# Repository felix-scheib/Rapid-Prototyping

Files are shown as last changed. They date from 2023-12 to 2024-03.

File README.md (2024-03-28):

# Rapid Prototyping

This is the repository with my prototype of [Rapid Prototyping](https://obs.fbi.h-da.de/mhb/modul.php?nr=30.2670&sem=20231) by [Prof. Dr. Stefan Rapp](https://fbi.h-da.de/personen/stefan-rapp/) in the winterterm 23/24.

The following tools are used to create the prototype:

- [PlatformIO](https://platformio.org/)
- [KiCad](https://www.kicad.org/)
- [FreeCAD](https://www.freecad.org/)

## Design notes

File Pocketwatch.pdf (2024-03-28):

# RAPID PROTOTYPING

Felix Scheib
WiSe 23/24
Prof. Dr. Stefan Rapp

# DIE IDEE

## ZIELSETZUNG

„Entangled Hearts“

- zwei Objekte, welche miteinander verbunden/“verschränkt“ sind
- Interaktion an einem Objekt ist am anderen sichtbar
- Kommunikation über weite Distanzen in „Echtzeit“ möglich
Felix Scheib - Rapid Prototyping - WiSe 23/24 | 3

## IDEENFINDUNG

Technik als Modeaccessoire

- Vorreiter: Apple
- Smartphones/Watches, Kopfhörer mehr als „nur“ Technik
- lange Schlangen vor Läden bei Verkaufsstart
- Technik Teil des Outfits, z.B. Kopfhörer

Retro/Vintage

- Technik wird „wiederbelebt“
- Beispiel: Schallplatten
- Mode und Frisuren aus vergangenen Jahrzehnten „kommen wieder“
- ältere (und einfachere) Lösungen oftmals robuster als
„overengineerte“ moderne Ansätze
Felix Scheib- Rapid Prototyping Prototyping - WiSe 23/24 | 4

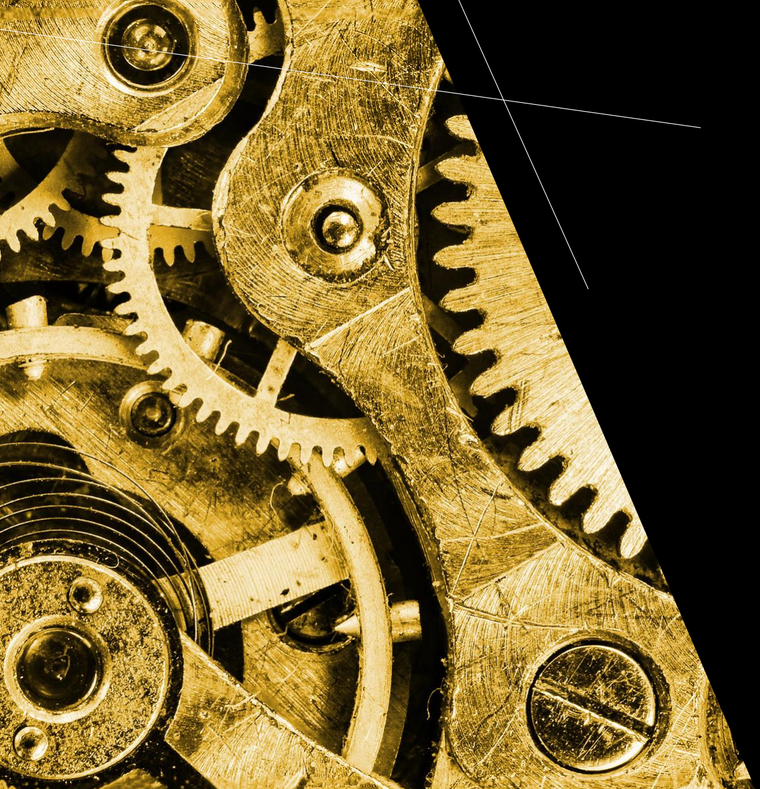
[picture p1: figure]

# THE NEXT „LITTLE“ THING

## POCKETWATCH 2.0

- Design einer klassischen Taschenuhr
- Display zum Anzeigen der Uhrzeit
- LED-Ring zur Kommunikation der Benutzer

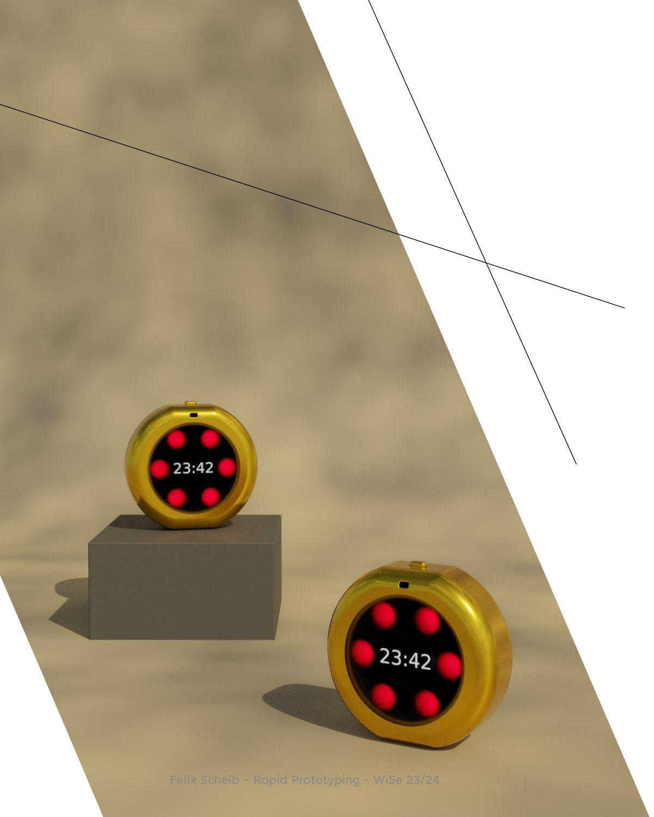
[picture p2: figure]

Felix Scheib - Rapid Prototyping - WiSe 23/24 | 6

## VORTEILE DER POCKETWATCH 2.0

Die Zeit ist ein fundamentaler Bestandteil unseres Alltags

- unser Alltag wird durch Termine strukturiert (z.B. Stundenplan)
- für die aktuelle Uhrzeit nutzt man hauptsächlich Smartphones und Smartwatches
- dauerhafte Präsenz dieser Geräte führt zur dauerhaften Erreichbarkeit (psychischer Stress)

Die Pocketwatch 2.0 führt zur Entschleunigung des Alltags!

Felix Scheib - Rapid Prototyping - WiSe 23/24 | 7

## TECHNISCHE UMSETZUNG

- (OLED) Display zum Anzeigen der Uhrzeit
- LED-Ring (Neopixel) zum Abspielen von Blinksequenzen
- Interaktion über Bewegungs- und Helligkeitssensor oder Taster
- Kommunikation mittels MQTT
- Aufladen des Akkus über USB-C
Felix Scheib - Rapid Prototyping - WiSe 23/24 | 8

## MATERIALKOSTEN

Position | Anzahl | Einzelpreis | Summe
Elektronik | 1 | 14,15€ | 14,15€
PCB | 1 | 0,41€ | 0,41€
Display | 1 | 1,27€ | 1,27€
MPU | 1 | 3,35€ | 3,35€
Glas | 1 | 2,10€ | 2,10€

PLA-
Filament | 42g | 0,03€ | 1,26€
Summe | | | 22,54€

Felix Scheib - Rapid Prototyping - WiSe 23/24

| | Anzahl | Einzelpreis | Summe
Kondensator | 470pF | 1 | 0,026 € | 0,026 €
| 0.1µF | 8 | 0,008 € | 0,064 €
| 470nF | 1 | 0,062 € | 0,062 €
| 1µF | 3 | 0,265 € | 0,795 €
| 4.7µF | 2 | 0,183 € | 0,366 €
| | | | 1,313 €
Widerstand | 330Ω | 2 | 0,001 € | 0,002 €
| 2kΩ | 1 | 0,001 € | 0,001 €
10kΩ | 4 | 0,001 € | 0,004 €
100kΩ | 1 | 0,001 € | 0,001 €
| | | 0,008 €
Licht | LED rot | 1 | 0,069 € | 0,069 €
Neopixel | 6 | 0,279 € | 1,671 €
Phototransistor | 1 | 0,279 € | 0,279 €
| | | 2,019 €
Konnektoren | Batterie | 1 | 0,274 € | 0,274 €
| Pin-Header 1x8 | 3 | 0,418 € | 1,254 €
USB-C | 1 | 0,331 € | 0,331 €
| | | 1,859 €
Schalter | Taster | 1 | 0,267 € | 0,267 €
| Schiebeschalter | 1 | 0,463 € | 0,463 €
| | | | 0,730 €
IC/MCU | Batterie Management | 1 | 0,593 € | 0,593 €
Leistungs Management | 1 | 0,207 € | 0,207 €
ESP32 | 1 | 3,240 € | 3,240 €
Akku | 1 | 4,180 € | 4,180 €
| | | 8,220 €
14,149 €

9

# SERIENMODELL

## FOKUS DES PROTOTYPS

- Platinen müssen per Hand zu löten sein (teilweise Einsatz von „Through-Hole“ Komponenten)
- einfacher Zugang zu Platinen im eingebauten Zustand
- Serielle Verbindung auch nach „Verlöten“ des Microchips (Pin-Header auf Rückseite)
- Gehäuse muss mit 3D-Drucker herstellbar sein
Felix Scheib - Rapid Prototyping - WiSe 23/24 | 11

## OPTIMIERUNGEN DES SERIENMODELLS

Haptik

- Materialwahl des Gehäuses (Metall, Composite)
- Herstellung des Gehäuses (Spritzguss, Fräsen)
- Gravur des Glases mit Laser
- Getöntes Glas
- Druckpunkt des Tasters

Elektronik

- nur Surface Mount (SMT)
Komponenten
- größerer Akku
- Passform des Akkus
- induktives Laden
- Solarpanel auf Rückseite
- (E)SIM statt WiFi für
Kommunikation
Felix Scheib Felix Scheib - Rapid Prototyping Prototyping - WiSe 23/24 | 12

# DEMONSTRATION DES PROTOTYPS

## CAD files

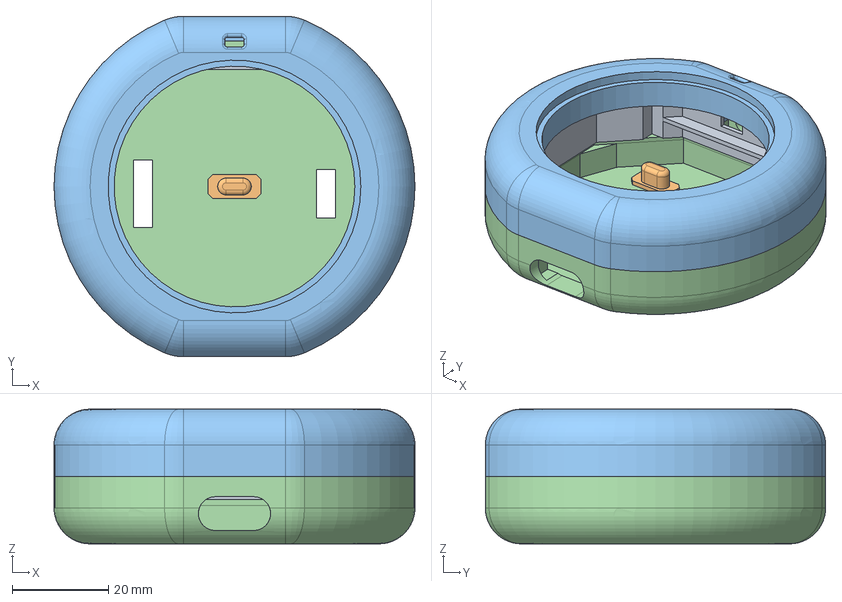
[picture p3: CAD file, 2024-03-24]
FreeCAD/EntangledHearts.FCStd
75.0 x 70.7 x 28.0 mm
Connector_Body
Button_Body
Top
Bottom

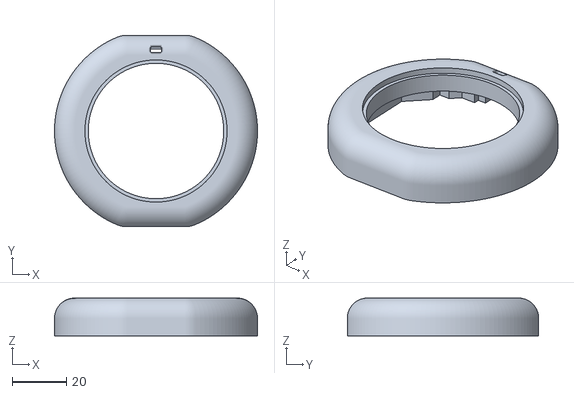
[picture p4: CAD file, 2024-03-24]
FreeCAD/STL/Top_Body.stl
75.0 x 70.7 x 14.0

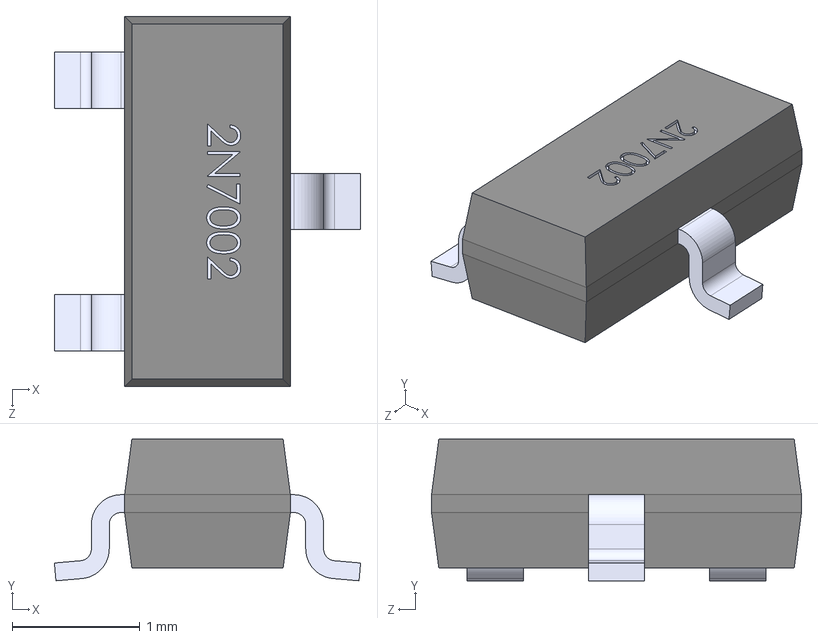
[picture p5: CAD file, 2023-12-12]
KiCad/_Libraries/2N7002/2N7002.stp
2.40 x 1.11 x 2.90 mm
2N7002_2
2N7002_3
2N7002_4
2N7002

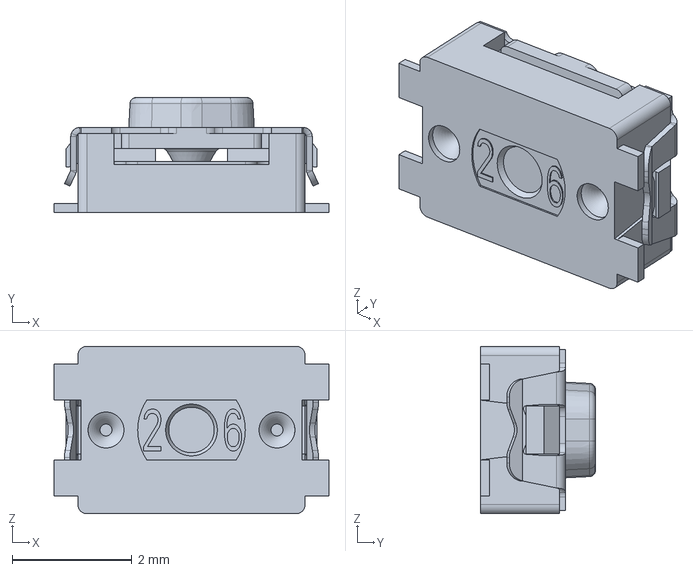
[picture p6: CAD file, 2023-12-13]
KiCad/_Libraries/KMR631NGULCLFS/KMR631NGULCLFS.stp
4.60 x 1.92 x 2.80 mm

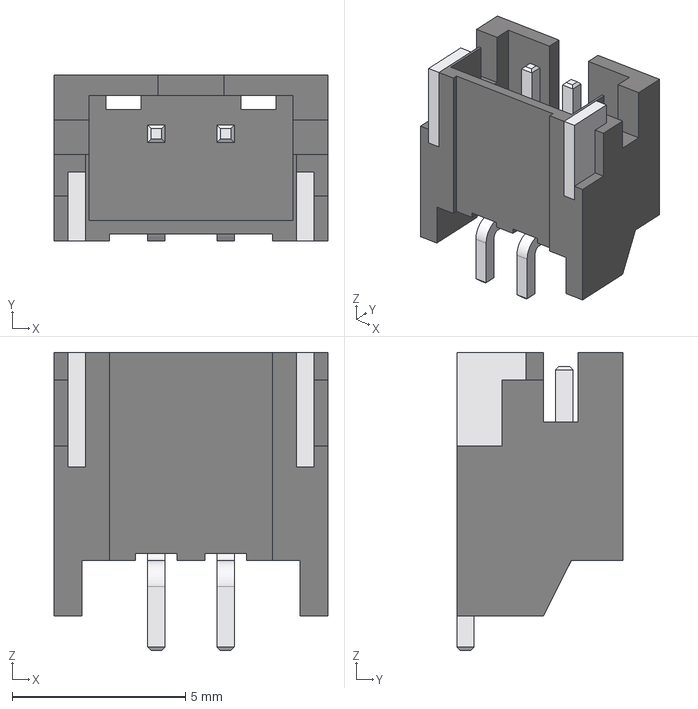
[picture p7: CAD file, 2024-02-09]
KiCad/_Libraries/S2B-PH-SM4-TB.stp
7.90 x 4.80 x 8.60 mm

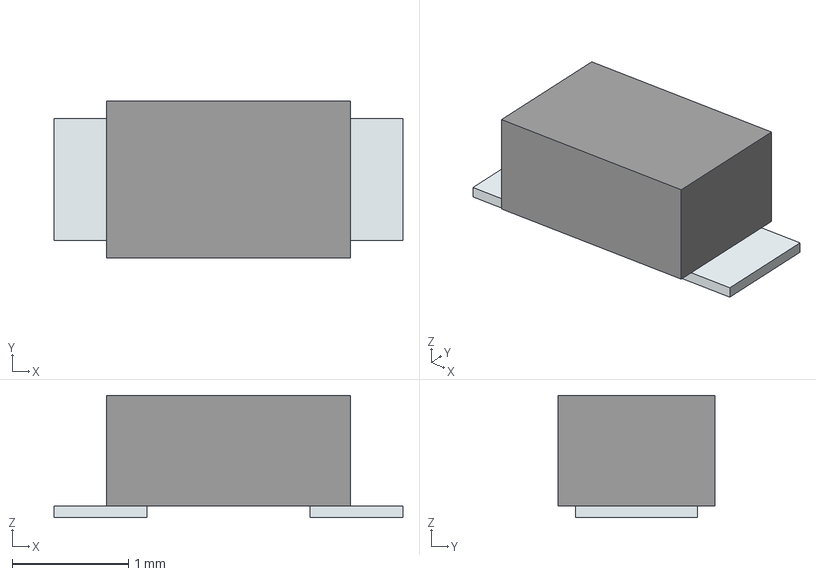
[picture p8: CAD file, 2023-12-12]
KiCad/_Libraries/SFH_3711/SFH_3711.stp
3.00 x 1.35 x 1.05 mm
Pins

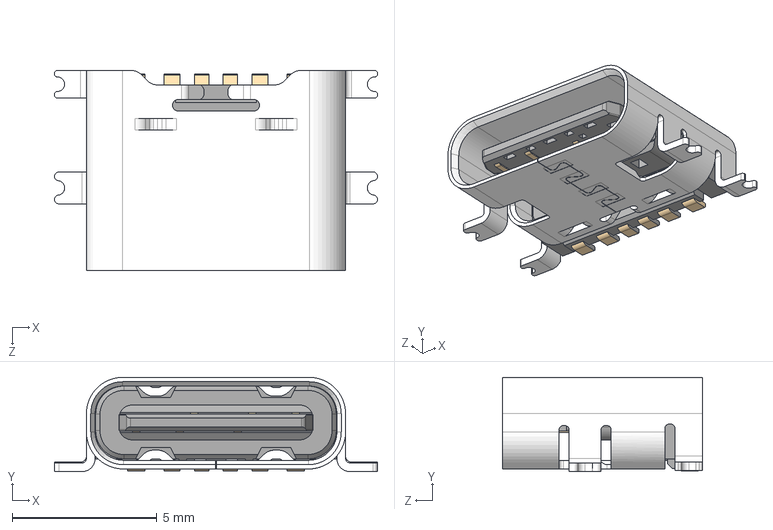
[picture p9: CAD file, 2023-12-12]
KiCad/_Libraries/USB4135-GF-A/USB4135-GF-A.stp
11.1 x 3.25 x 6.90 mm
USB4135-GF-A
USB4135-GF-A_2

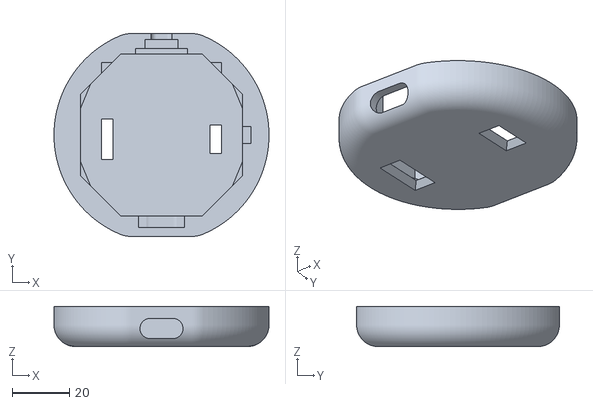
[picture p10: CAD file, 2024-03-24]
FreeCAD/STL/Bottom_Body.stl
75.0 x 70.7 x 14.0

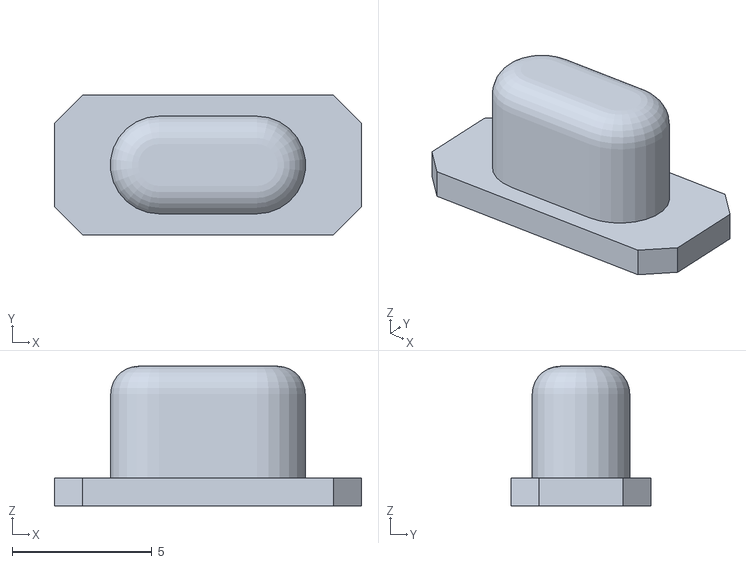
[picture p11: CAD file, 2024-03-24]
FreeCAD/STL/Button_Body.stl
11.0 x 5.00 x 5.00

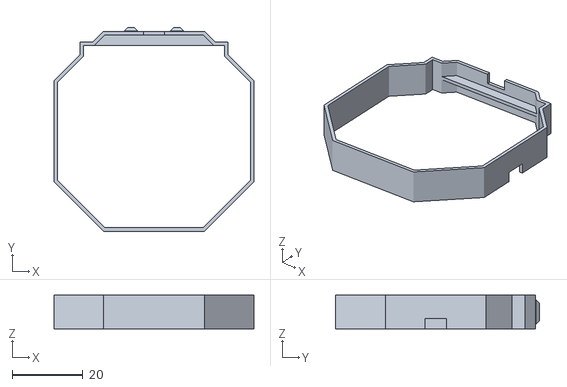
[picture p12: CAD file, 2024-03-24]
FreeCAD/STL/Connector_Body.stl
56.6 x 57.6 x 9.60

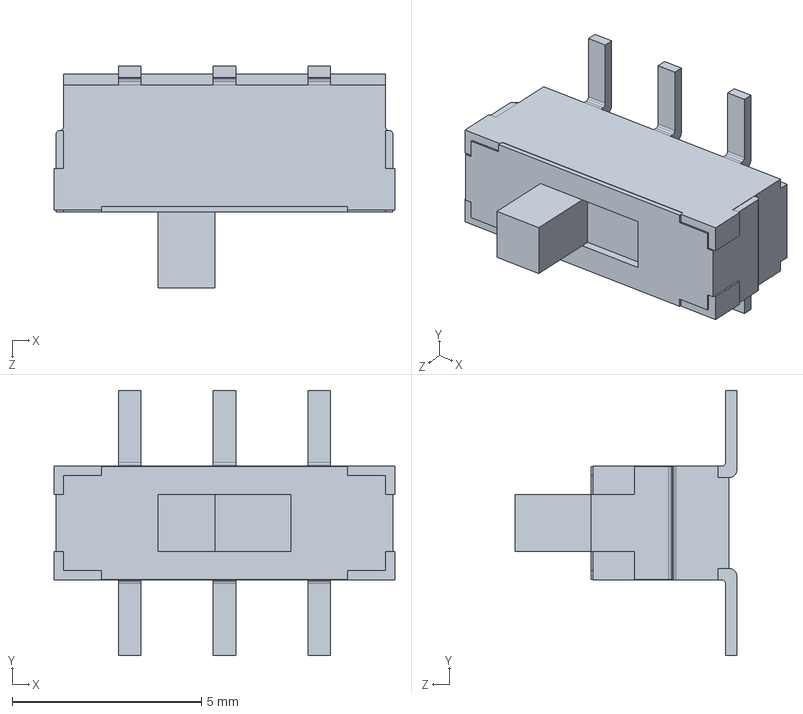
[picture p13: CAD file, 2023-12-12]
KiCad/_Libraries/JS202011SCQN/JS202011SCQN.stp
9.00 x 7.00 x 5.85 mm

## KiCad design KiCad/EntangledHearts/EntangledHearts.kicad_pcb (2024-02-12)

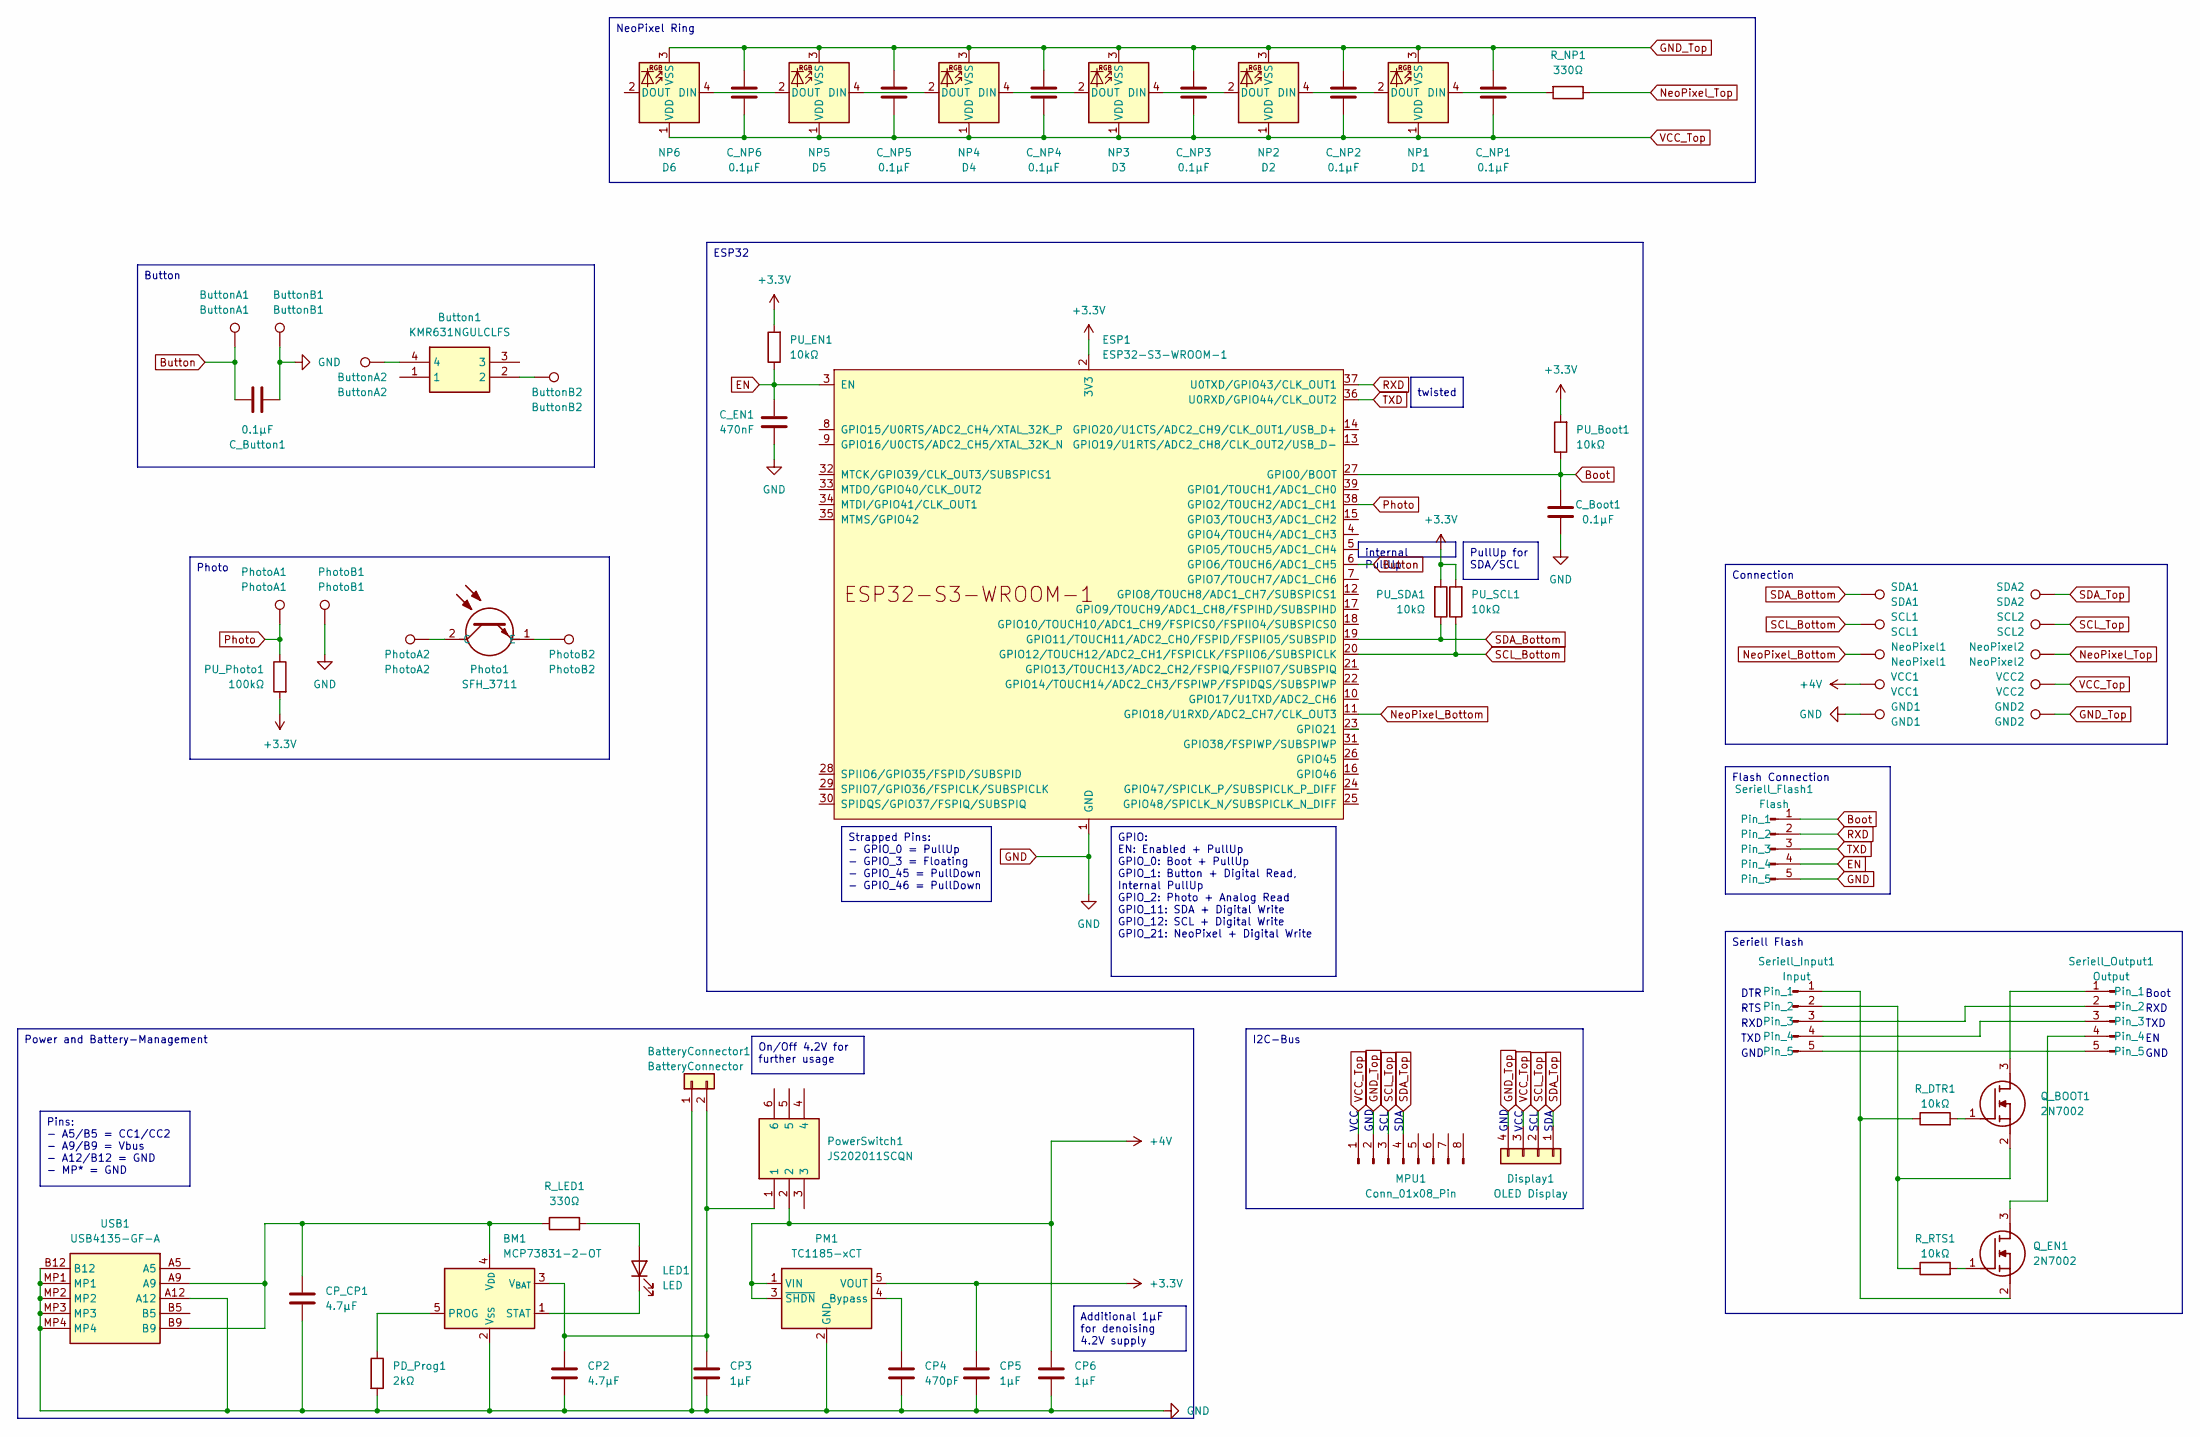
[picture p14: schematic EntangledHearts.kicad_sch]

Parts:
BM1: MCP73831-2-OT; SOT-23-5
BatteryConnector1: BatteryConnector; JST_PH_S2B-PH-SM4-TB_1x02-1MP_P2.00mm_Horizontal
Button1: KMR631NGULCLFS; KMR621NG; Mouser Part Number 611-KMR631NGULCLFS
ButtonA1: ButtonA1; TestPoint_Pad_1.5x1.5mm
ButtonA2: ButtonA2; TestPoint_Pad_1.5x1.5mm
ButtonB1: ButtonB1; TestPoint_Pad_1.5x1.5mm
ButtonB2: ButtonB2; TestPoint_Pad_1.5x1.5mm
CP2: 4.7µF; C_0805_2012Metric
CP3, CP5, CP6: 1µF; C_0805_2012Metric
CP4: 470pF; C_0805_2012Metric
CP_CP1: 4.7µF; C_0805_2012Metric
C_Boot1: 0.1µF; C_0805_2012Metric
C_Button1: 0.1µF; C_0805_2012Metric
C_EN1: 470nF; C_0805_2012Metric
C_NP1, C_NP2, C_NP3, C_NP4, C_NP5, C_NP6: 0.1µF; C_0805_2012Metric
D1: NP1; LED_WS2812B_PLCC4_5.0x5.0mm_P3.2mm
D2: NP2; LED_WS2812B_PLCC4_5.0x5.0mm_P3.2mm
D3: NP3; LED_WS2812B_PLCC4_5.0x5.0mm_P3.2mm
D4: NP4; LED_WS2812B_PLCC4_5.0x5.0mm_P3.2mm
D5: NP5; LED_WS2812B_PLCC4_5.0x5.0mm_P3.2mm
D6: NP6; LED_WS2812B_PLCC4_5.0x5.0mm_P3.2mm
Display1: OLED Display; PinHeader_1x04_P2.54mm_Vertical
ESP1: ESP32-S3-WROOM-1
GND1: GND1; TestPoint_Pad_1.5x1.5mm
GND2: GND2; TestPoint_Pad_1.5x1.5mm
LED1: LED; LED_0805_2012Metric
MPU1: Conn_01x08_Pin; PinHeader_1x08_P2.54mm_Vertical_SMD_Pin1Left
NeoPixel1: NeoPixel1; TestPoint_Pad_1.5x1.5mm
NeoPixel2: NeoPixel2; TestPoint_Pad_1.5x1.5mm
PD_Prog1: 2kΩ; R_0805_2012Metric
PM1: TC1185-xCT; SOT-23-5
PU_Boot1: 10kΩ; R_0805_2012Metric
PU_EN1: 10kΩ; R_0805_2012Metric
PU_Photo1: 100kΩ; R_0805_2012Metric
PU_SCL1: 10kΩ; R_0805_2012Metric
PU_SDA1: 10kΩ; R_0805_2012Metric
Photo1: SFH_3711; SFH3711; Mouser Part Number 720-SFH3711
PhotoA1: PhotoA1; TestPoint_Pad_1.5x1.5mm
PhotoA2: PhotoA2; TestPoint_Pad_1.5x1.5mm
PhotoB1: PhotoB1; TestPoint_Pad_1.5x1.5mm
PhotoB2: PhotoB2; TestPoint_Pad_1.5x1.5mm
PowerSwitch1: JS202011SCQN; Mouser Part Number 611-JS202011SCQN
Q_BOOT1: 2N7002; SOT96P240X120-3N; Manufacturer_Part_Number 2N7002; Mouser Part Number 512-2N7002
Q_EN1: 2N7002; SOT96P240X120-3N; Manufacturer_Part_Number 2N7002; Mouser Part Number 512-2N7002
R_DTR1: 10kΩ; R_0805_2012Metric
R_LED1: 330Ω; R_0805_2012Metric
R_NP1: 330Ω; R_0805_2012Metric
R_RTS1: 10kΩ; R_0805_2012Metric
SCL1: SCL1; TestPoint_Pad_1.5x1.5mm
SCL2: SCL2; TestPoint_Pad_1.5x1.5mm
SDA1: SDA1; TestPoint_Pad_1.5x1.5mm
SDA2: SDA2; TestPoint_Pad_1.5x1.5mm
Seriell_Flash1: Flash; PinHeader_1x05_P2.54mm_Vertical_SMD_Pin1Left
Seriell_Input1: Input; PinHeader_1x05_P2.54mm_Vertical_SMD_Pin1Left
Seriell_Output1: Output; PinHeader_1x05_P2.54mm_Vertical_SMD_Pin1Left
USB1: USB4135-GF-A; USB4135GFA; Mouser Part Number 640-USB4135-GF-A
VCC1: VCC1; TestPoint_Pad_1.5x1.5mm
VCC2: VCC2; TestPoint_Pad_1.5x1.5mm

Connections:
+3.3V: CP5.1, ESP1.2 (3V3), PM1.5 (VOUT), PU_Boot1.2, PU_EN1.2, PU_Photo1.2, PU_SCL1.2, PU_SDA1.2
+4V: CP6.1, PM1.1 (VIN), PM1.3 (~SHDN), PowerSwitch1.2, VCC1.1
Boot: C_Boot1.2, ESP1.27 (GPIO0/BOOT), PU_Boot1.1, Seriell_Flash1.1
Button: ButtonA1.1, C_Button1.1, ESP1.6 (GPIO6/TOUCH6/ADC1_CH5)
EN: C_EN1.2, ESP1.3 (EN), PU_EN1.1, Seriell_Flash1.4
GND: BM1.2 (V_{SS}), BatteryConnector1.1, ButtonB1.1, CP2.2, CP3.2, CP4.2, CP5.2, CP6.2, CP_CP1.2, C_Boot1.1, C_Button1.2, C_EN1.1, ESP1.1 (GND), ESP1.40 (GND), ESP1.41 (GND), GND1.1, PD_Prog1.2, PM1.2 (GND), PhotoB1.1, Seriell_Flash1.5, USB1.A12, USB1.B12, USB1.MP1, USB1.MP2, USB1.MP3, USB1.MP4
GND_Top: C_NP1.2, C_NP2.2, C_NP3.2, C_NP4.2, C_NP5.2, C_NP6.2, D1.3 (VSS), D2.3 (VSS), D3.3 (VSS), D4.3 (VSS), D5.3 (VSS), D6.3 (VSS), Display1.4, GND2.1, MPU1.2
NeoPixel_Bottom: ESP1.11 (GPIO18/U1RXD/ADC2_CH7/CLK_OUT3), NeoPixel1.1
NeoPixel_Top: NeoPixel2.1, R_NP1.1
unnamed: BM1.5 (PROG), PD_Prog1.1
unnamed: BM1.1 (STAT), LED1.1 (K)
unnamed: BM1.3 (V_{BAT}), BatteryConnector1.2, CP2.1, CP3.1, PowerSwitch1.1
unnamed: BM1.4 (V_{DD}), CP_CP1.1, R_LED1.1, USB1.A9, USB1.B9
unnamed: Button1.2, ButtonB2.1
unnamed: Button1.4, ButtonA2.1
unnamed: D1.4 (DIN), R_NP1.2
unnamed: D1.2 (DOUT), D2.4 (DIN)
unnamed: D2.2 (DOUT), D3.4 (DIN)
unnamed: D3.2 (DOUT), D4.4 (DIN)
unnamed: D4.2 (DOUT), D5.4 (DIN)
unnamed: D5.2 (DOUT), D6.4 (DIN)
unnamed: LED1.2 (A), R_LED1.2
unnamed: CP4.1, PM1.4 (Bypass)
unnamed: Photo1.2 (C), PhotoA2.1
unnamed: Photo1.1 (E), PhotoB2.1
unnamed: Q_BOOT1.3 (D), Seriell_Output1.1
unnamed: Q_BOOT1.1 (G), R_DTR1.2
unnamed: Q_BOOT1.2 (S), R_RTS1.1, Seriell_Input1.2
unnamed: Q_EN1.3 (D), Seriell_Output1.4
unnamed: Q_EN1.1 (G), R_RTS1.2
unnamed: Q_EN1.2 (S), R_DTR1.1, Seriell_Input1.1
unnamed: Seriell_Input1.3, Seriell_Output1.2
unnamed: Seriell_Input1.4, Seriell_Output1.3
unnamed: Seriell_Input1.5, Seriell_Output1.5
Photo: ESP1.38 (GPIO2/TOUCH2/ADC1_CH1), PU_Photo1.1, PhotoA1.1
RXD: ESP1.37 (U0TXD/GPIO43/CLK_OUT1), Seriell_Flash1.2
SCL_Bottom: ESP1.20 (GPIO12/TOUCH12/ADC2_CH1/FSPICLK/FSPIIO6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), PU_SCL1.1, SCL1.1
SCL_Top: Display1.2, MPU1.3, SCL2.1
SDA_Bottom: ESP1.19 (GPIO11/TOUCH11/ADC2_CH0/FSPID/FSPIIO5/S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), PU_SDA1.1, SDA1.1
SDA_Top: Display1.1, MPU1.4, SDA2.1
TXD: ESP1.36 (U0RXD/GPIO44/CLK_OUT2), Seriell_Flash1.3
VCC_Top: C_NP1.1, C_NP2.1, C_NP3.1, C_NP4.1, C_NP5.1, C_NP6.1, D1.1 (VDD), D2.1 (VDD), D3.1 (VDD), D4.1 (VDD), D5.1 (VDD), D6.1 (VDD), Display1.3, MPU1.1, VCC2.1

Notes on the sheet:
Additional 1µF for denoising 4.2V supply
Pins: - A5/B5 = CC1/CC2 - A9/B9 = Vbus - A12/B12 = GND - MP* = GND
On/Off 4.2V for further usage
Power and Battery-Management
Photo
I2C-Bus
ESP32
internal PullUp
PullUp for SDA/SCL
GPIO: EN: Enabled + PullUp GPIO_0: Boot + PullUp GPIO_1: Button + Digital Read, Internal PullUp GPIO_2: Photo + Analog Read GPIO_11: SDA + Digital Write GPIO_12: SCL + Digital Write GPIO_21: NeoPixel + Digital Write
Flash Connection
twisted
Seriell Flash
Connection
Strapped Pins: - GPIO_0 = PullUp - GPIO_3 = Floating - GPIO_45 = PullDown - GPIO_46 = PullDown
Button
NeoPixel Ring
TXD
SCL
GND
RXD
VCC
DTR
SDA
RTS
Boot

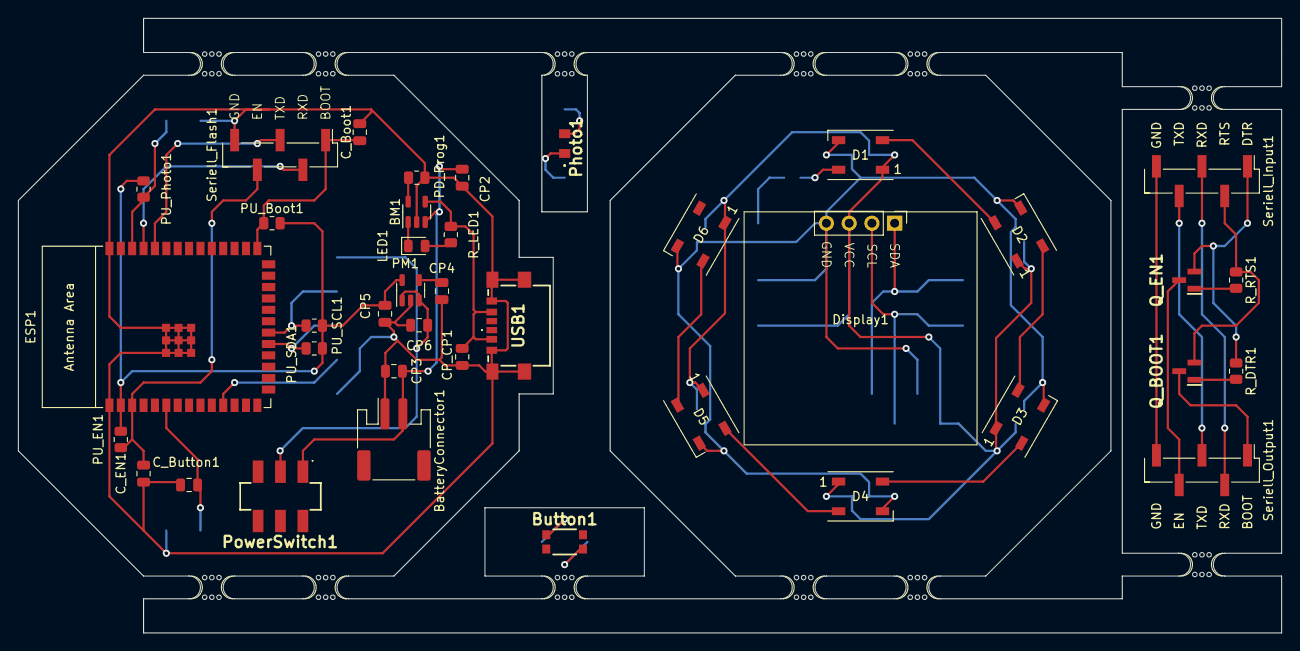
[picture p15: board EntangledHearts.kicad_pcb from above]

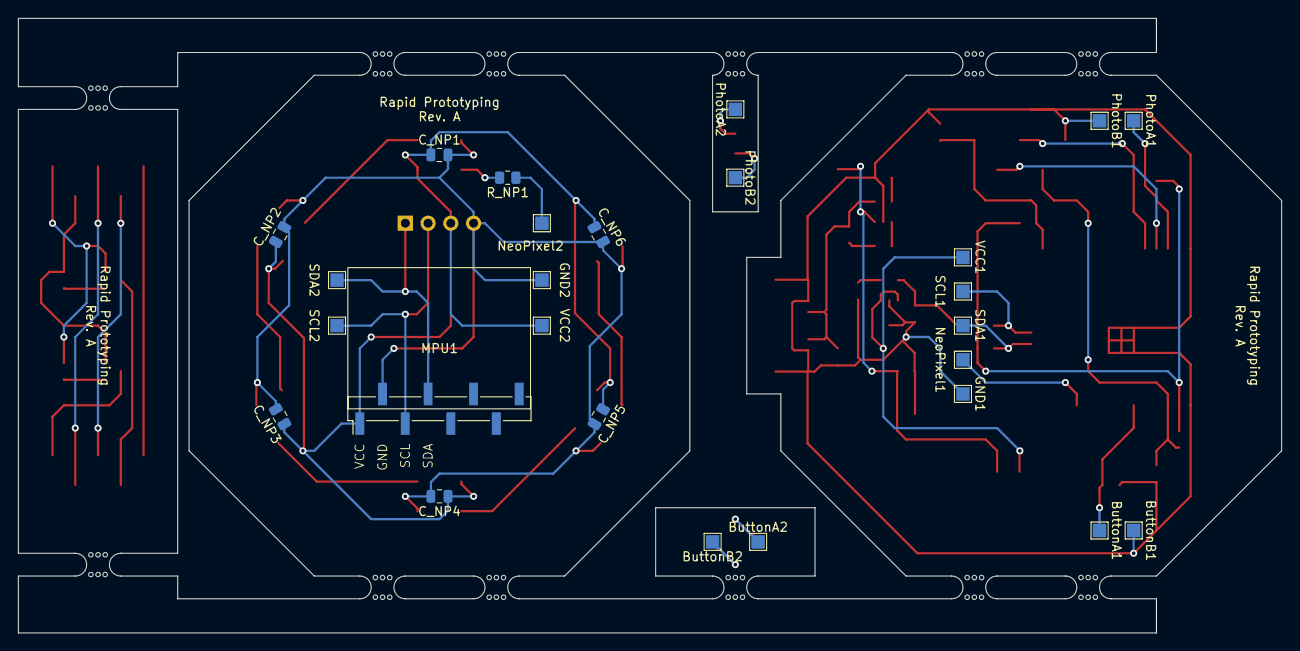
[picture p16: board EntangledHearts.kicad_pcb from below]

Board: 2 copper layers, 141.0 x 68.6 mm, 77 parts (26 on the bottom side), 42 nets.

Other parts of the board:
mouse-bite-2.54mm-slot, mouse-bite-2.54mm-slot#2, mouse-bite-2.54mm-slot#3, mouse-bite-2.54mm-slot#4, mouse-bite-2.54mm-slot#5, mouse-bite-2.54mm-slot#6, mouse-bite-2.54mm-slot#7, mouse-bite-2.54mm-slot#8, mouse-bite-2.54mm-slot#9, mouse-bite-2.54mm-slot#10, mouse-bite-2.54mm-slot#11, mouse-bite-2.54mm-slot#12: VAL**; mouse-bite-2.54mm-slot

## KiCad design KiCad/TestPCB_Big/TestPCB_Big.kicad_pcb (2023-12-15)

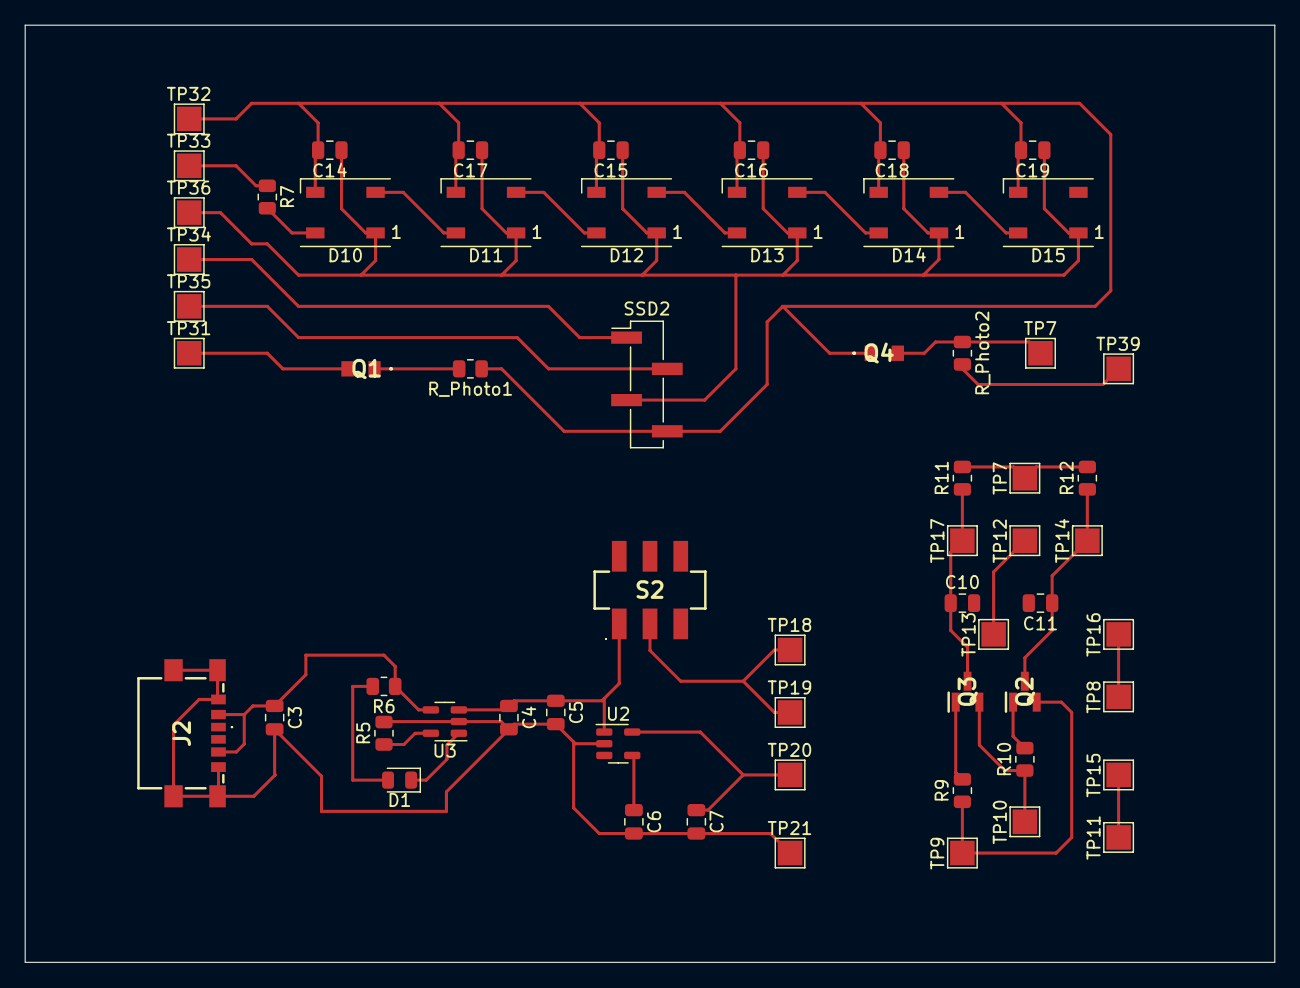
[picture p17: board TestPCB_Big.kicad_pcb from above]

Board: 2 copper layers, 101.6 x 76.2 mm, 61 parts (0 on the bottom side), 35 nets.

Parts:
C3, C4: 4.7µF; C_0805_2012Metric
C5, C7: 1µF; C_0805_2012Metric
C6: 470pF; C_0805_2012Metric
C10, C14, C15, C16, C17, C18, C19: 0.1µF; C_0805_2012Metric
C11: 470nF; C_0805_2012Metric
D1: LED; LED_0805_2012Metric
D10, D11, D12, D13, D14, D15: WS2812B; LED_WS2812B_PLCC4_5.0x5.0mm_P3.2mm
J2: USB4135-GF-A; USB4135GFA
Q1, Q4: SFH_3711; SFH3711
Q2, Q3: 2N7002; SOT96P240X120-3N
R5: 2kΩ; R_0805_2012Metric
R6, R7: 330Ω; R_0805_2012Metric
R9, R10, R11, R12: 10kΩ; R_0805_2012Metric
R_Photo1: 0Ω; R_0805_2012Metric
R_Photo2: 10kΩ; R_0805_2012Metric
S2: JS202011SCQN
SSD2: Conn_01x04_Pin; PinHeader_1x04_P2.54mm_Vertical_SMD_Pin1Left
TP7, TP20: +3.3V; TestPoint_Pad_2.0x2.0mm
TP7#2: GPIO_Photo2; TestPoint_Pad_2.0x2.0mm
TP8: TXD; TestPoint_Pad_2.0x2.0mm
TP9: DTR; TestPoint_Pad_2.0x2.0mm
TP10: RTS; TestPoint_Pad_2.0x2.0mm
TP11: RXD; TestPoint_Pad_2.0x2.0mm
TP12, TP21, TP32: GND; TestPoint_Pad_2.0x2.0mm
TP13: FL_GND; TestPoint_Pad_2.0x2.0mm
TP14: FL_EN; TestPoint_Pad_2.0x2.0mm
TP15: FL_RXD; TestPoint_Pad_2.0x2.0mm
TP16: FL_TXD; TestPoint_Pad_2.0x2.0mm
TP17: FL_RST; TestPoint_Pad_2.0x2.0mm
TP18: +4.2V; TestPoint_Pad_2.0x2.0mm
TP19: VBat; TestPoint_Pad_2.0x2.0mm
TP31: GPIO_Photo1; TestPoint_Pad_2.0x2.0mm
TP33: GPIO_Pixel; TestPoint_Pad_2.0x2.0mm
TP34: SDA; TestPoint_Pad_2.0x2.0mm
TP35: SCL; TestPoint_Pad_2.0x2.0mm
TP36: +4.4V; TestPoint_Pad_2.0x2.0mm
TP39: +3.3V Photo; TestPoint_Pad_2.0x2.0mm
U2: TC1185-xCT; SOT-23-5
U3: MCP73831-2-OT; SOT-23-5

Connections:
unnamed: C10.2, C11.2
unnamed: D1.2 (A), R6.2
unnamed: D1.1 (K), U3.1 (STAT)
unnamed: D10.4 (DIN), R7.2
unnamed: D10.2 (DOUT), D11.4 (DIN)
unnamed: C14.1, C15.1, C16.1, C17.1, C18.1, C19.1, D10.1 (VDD), D11.1 (VDD), D12.1 (VDD), D13.1 (VDD), D14.1 (VDD), D15.1 (VDD), SSD2.3, TP36.1
unnamed: C14.2, C15.2, C16.2, C17.2, C18.2, C19.2, D10.3 (VSS), D11.3 (VSS), D12.3 (VSS), D13.3 (VSS), D14.3 (VSS), D15.3 (VSS), Q4.1 (E), R_Photo1.1, SSD2.4, TP32.1
unnamed: D11.2 (DOUT), D12.4 (DIN)
unnamed: D12.2 (DOUT), D13.4 (DIN)
unnamed: D13.2 (DOUT), D14.4 (DIN)
unnamed: D14.2 (DOUT), D15.4 (DIN)
unnamed: Q1.2 (C), TP31.1
unnamed: Q1.1 (E), R_Photo1.2
unnamed: C11.1, Q2.3 (D), R12.1, TP14.1
unnamed: Q2.1 (G), R10.2
unnamed: Q2.2 (S), R9.1, TP9.1
unnamed: C10.1, Q3.3 (D), R11.1, TP17.1
unnamed: Q3.1 (G), R9.2
unnamed: Q3.2 (S), R10.1, TP10.1
unnamed: Q4.2 (C), R_Photo2.1, TP7#2.1
unnamed: R7.1, TP33.1
unnamed: R11.2, R12.2, TP7.1
unnamed: R_Photo2.2, TP39.1
unnamed: S2.2, TP18.1, TP19.1
unnamed: SSD2.1, TP34.1
unnamed: SSD2.2, TP35.1
unnamed: TP11.1, TP15.1
unnamed: TP12.1, TP13.1
unnamed: TP8.1, TP16.1
unnamed: C6.1, U2.4 (Bypass)
unnamed: C3.2, C4.2, C5.2, C6.2, C7.2, J2.A12, J2.B12, J2.MP1, J2.MP2, J2.MP3, J2.MP4, R5.2, TP21.1, U2.2 (GND), U3.2 (V_{SS})
unnamed: C4.1, C5.1, S2.1, U2.1 (VIN), U2.3 (~SHDN), U3.3 (V_{BAT})
unnamed: C7.1, TP20.1, U2.5 (VOUT)
unnamed: R5.1, U3.5 (PROG)
unnamed: C3.1, J2.A9, J2.B9, R6.1, U3.4 (V_{DD})

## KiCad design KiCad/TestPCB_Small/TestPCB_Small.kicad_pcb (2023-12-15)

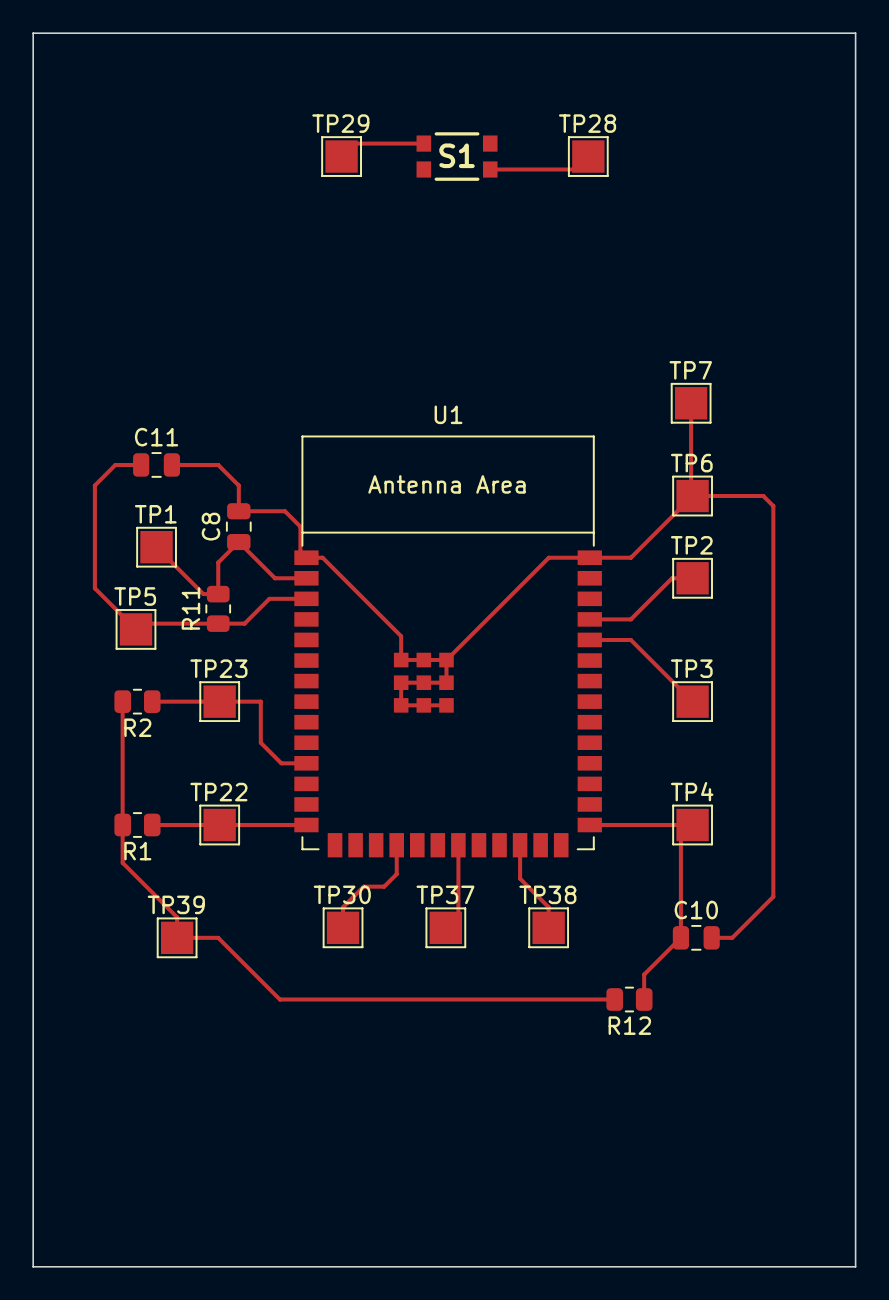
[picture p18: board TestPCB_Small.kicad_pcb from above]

Board: 2 copper layers, 50.8 x 76.2 mm, 24 parts (0 on the bottom side), 13 nets.

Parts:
C8, C10: 0.1µF; C_0805_2012Metric
C11: 470nF; C_0805_2012Metric
R1, R2, R11, R12: 10kΩ; R_0805_2012Metric
S1: KMR631NGULCLFS; KMR621NG
TP1, TP39: +3.3V; TestPoint_Pad_2.0x2.0mm
TP2: FL_RXD; TestPoint_Pad_2.0x2.0mm
TP3: FL_TXD; TestPoint_Pad_2.0x2.0mm
TP4: FL_RST; TestPoint_Pad_2.0x2.0mm
TP5: FL_EN; TestPoint_Pad_2.0x2.0mm
TP6, TP28: GND; TestPoint_Pad_2.0x2.0mm
TP7: FL_GND; TestPoint_Pad_2.0x2.0mm
TP22: SCL; TestPoint_Pad_2.0x2.0mm
TP23: SDA; TestPoint_Pad_2.0x2.0mm
TP29, TP30: GPIO_Switch; TestPoint_Pad_2.0x2.0mm
TP37: GPIO_Photo; TestPoint_Pad_2.0x2.0mm
TP38: GPIO_Pixel; TestPoint_Pad_2.0x2.0mm
U1: ESP32-S3-WROOM-1

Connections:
unnamed: C8.2, C10.2, C11.2, TP6.1, TP7.1, U1.1 (GND), U1.40 (GND), U1.41 (GND)
unnamed: S1.2, TP28.1
unnamed: S1.4, TP29.1
unnamed: C8.1, R1.2, R2.2, R11.2, R12.2, TP1.1, TP39.1, U1.2 (3V3)
unnamed: C11.1, R11.1, TP5.1, U1.3 (EN)
unnamed: C10.1, R12.1, TP4.1, U1.27 (GPIO0/BOOT)
unnamed: TP30.1, U1.18 (GPIO10/TOUCH10/ADC1_CH9/FSPICS0/FSPIIO4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)
unnamed: TP37.1, U1.21 (GPIO13/TOUCH13/ADC2_CH2/FSPIQ/FSPIIO7/S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)
unnamed: R2.1, TP23.1, U1.11 (GPIO18/U1RXD/ADC2_CH7/CLK_OUT3)
unnamed: R1.1, TP22.1, U1.14 (GPIO20/U1CTS/ADC2_CH9/CLK_OUT1/USB_D+)
unnamed: TP38.1, U1.24 (GPIO47/SPICLK_P/SUBSPICLK_P_DIFF)
unnamed: TP3.1, U1.36 (U0RXD/GPIO44/CLK_OUT2)
unnamed: TP2.1, U1.37 (U0TXD/GPIO43/CLK_OUT1)

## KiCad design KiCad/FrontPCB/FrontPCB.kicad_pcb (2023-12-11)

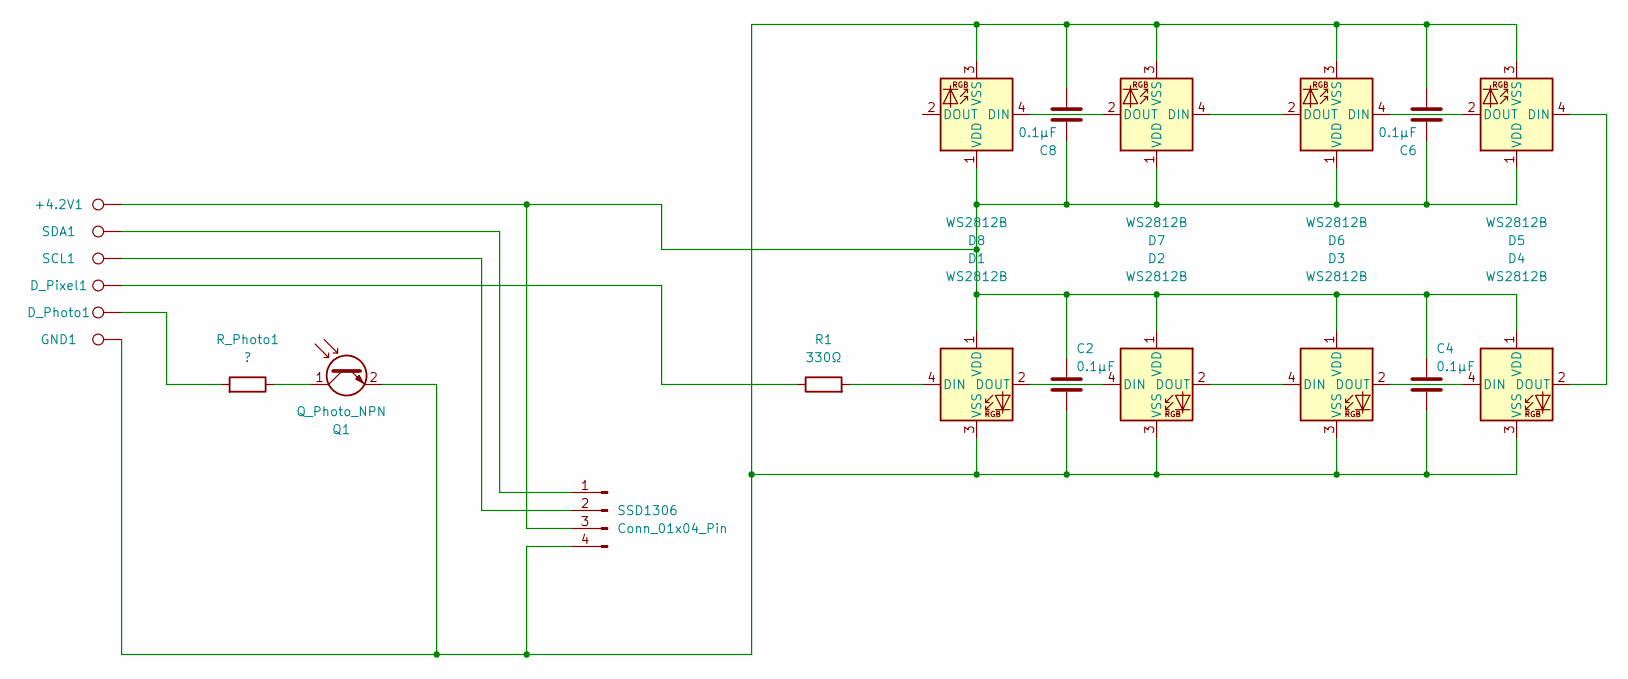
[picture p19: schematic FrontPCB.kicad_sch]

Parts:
+4.2V1: TestPoint; TestPoint_Pad_2.0x2.0mm
C2, C4, C6, C8: 0.1µF; C_0805_2012Metric
D1, D2, D3, D4, D5, D6, D7, D8: WS2812B; LED_WS2812B_PLCC4_5.0x5.0mm_P3.2mm
D_Photo1: TestPoint; TestPoint_Pad_2.0x2.0mm
D_Pixel1: TestPoint; TestPoint_Pad_2.0x2.0mm
GND1: TestPoint; TestPoint_Pad_2.0x2.0mm
Q1: Q_Photo_NPN; LED_0805_2012Metric
R1: 330Ω; R_0805_2012Metric
R_Photo1: ?; R_0805_2012Metric
SCL1: TestPoint; TestPoint_Pad_2.0x2.0mm
SDA1: TestPoint; TestPoint_Pad_2.0x2.0mm
SSD1306: Conn_01x04_Pin; PinHeader_1x04_P2.54mm_Vertical_SMD_Pin1Left

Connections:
unnamed: D1.4 (DIN), R1.2
unnamed: D1.2 (DOUT), D2.4 (DIN)
unnamed: +4.2V1.1, C2.1, C4.1, C6.1, C8.1, D1.1 (VDD), D2.1 (VDD), D3.1 (VDD), D4.1 (VDD), D5.1 (VDD), D6.1 (VDD), D7.1 (VDD), D8.1 (VDD), SSD1306.3
unnamed: C2.2, C4.2, C6.2, C8.2, D1.3 (VSS), D2.3 (VSS), D3.3 (VSS), D4.3 (VSS), D5.3 (VSS), D6.3 (VSS), D7.3 (VSS), D8.3 (VSS), GND1.1, Q1.2 (E), SSD1306.4
unnamed: D2.2 (DOUT), D3.4 (DIN)
unnamed: D3.2 (DOUT), D4.4 (DIN)
unnamed: D4.2 (DOUT), D5.4 (DIN)
unnamed: D5.2 (DOUT), D6.4 (DIN)
unnamed: D6.2 (DOUT), D7.4 (DIN)
unnamed: D7.2 (DOUT), D8.4 (DIN)
unnamed: D_Photo1.1, R_Photo1.2
unnamed: D_Pixel1.1, R1.1
unnamed: Q1.1 (C), R_Photo1.1
unnamed: SDA1.1, SSD1306.1
unnamed: SCL1.1, SSD1306.2

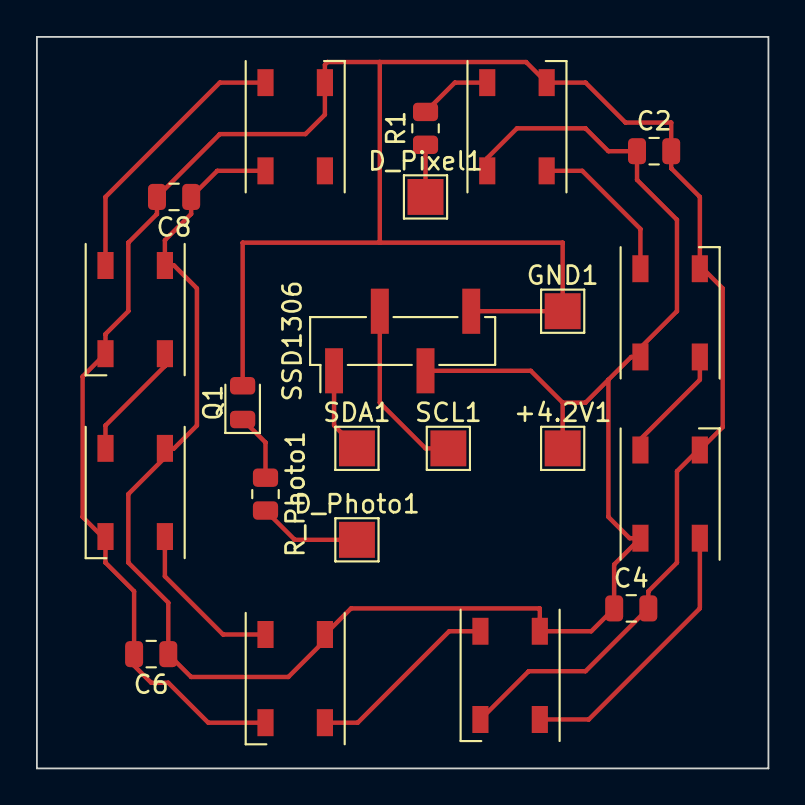
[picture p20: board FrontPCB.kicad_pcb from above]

Board: 2 copper layers, 40.6 x 40.6 mm, 22 parts (0 on the bottom side), 15 nets.

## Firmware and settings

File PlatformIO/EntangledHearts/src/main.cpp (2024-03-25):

#include <Arduino.h>

#include <Adafruit_NeoPixel.h>
#ifdef __AVR__
#include <avr/power.h>
#endif

#include <Wire.h>

#include <WiFi.h>

#include "credentials.h"
#include "gpio_mapping.h"

#include "display.h"
#include "mpu.h"
#include "mqtt.h"
#include "neopixel.h"
#include "ntp.h"

#define BAUD_RATE 9600

#define PIXELS 6

static const uint16_t INTENSITY_THRESHOLD = 100;
static const uint16_t BRIGHTNESS_MAX = 4095;

static unsigned long ACTIVE_TIME = 10 * 1000;


uint8_t previous_state = HIGH;
uint8_t current_state = HIGH;

WiFiClient wiFiClient{};
Mqtt mqttClient{wiFiClient, HOSTNAME, SUB_TOPIC};

Display display{};

Mpu mpu{};

Neopixel neopixel{GPIO_NEOPIXEL, PIXELS};

void callback(char* topic, byte* payload, unsigned int length);

uint16_t get_intensity();

static bool pair_signal = false;
static bool button_pressed = false;

static bool attraction_mode = false;

static unsigned long start_time = 0;
static unsigned long ellapsed_time = 0;

void setup() {
    // Setup PinModes
    pinMode(GPIO_BUTTON, INPUT_PULLUP);
    pinMode(GPIO_PHOTO, ANALOG);
    pinMode(GPIO_NEOPIXEL, OUTPUT);

    Wire.begin(GPIO_SDA, GPIO_SCL);

    // Setup of Seriell-Connection
    Serial.begin(BAUD_RATE);
    while (!Serial);

    // Setup WiFi
    WiFi.setHostname(HOSTNAME.c_str());
    WiFi.begin(WIFI_SSID.c_str(), WIFI_PASS.c_str());

    while (WiFi.status() != WL_CONNECTED) {
        delay(500);
        Serial.println("Next attempt to connect WiFi...");
    }

    // Setup time
    fetch_time();
    Serial.printf("%02d:%02d:%02d\n", hour(), minute(), second());

    // Setup display
    display.setup();

    // Setup mpu
    mpu.setup();

    // Setup MQTT
    mqttClient.setup(MQTT_BROKER,  MQTT_PORT, callback);
    mqttClient.reconnect();

    // NeoPixel
    neopixel.setup();
}

void loop() {
    display.update();

    if (!mqttClient.client.connected()) {
        mqttClient.reconnect();
    }

    mqttClient.client.loop();  

    if (!attraction_mode) {
        uint32_t intensity = get_intensity();
        bool is_bright = (intensity > INTENSITY_THRESHOLD);

        bool is_movement = mpu.update();

        bool button_pressed = (digitalRead(GPIO_BUTTON) == LOW);

        if ((is_bright && is_movement) || button_pressed) {
            Serial.print("Enable Display by: ");

            if ((is_bright && is_movement)) {
                Serial.println("movement");
            }

            if (button_pressed) {
                Serial.println("button");
            }

            mqttClient.client.publish(PUB_TOPIC.c_str(), "y");

            display.display.setContrast(255);
            attraction_mode = true;

            start_time = millis();
        }
    } else {
        if ((millis() - start_time) > ACTIVE_TIME) {
            Serial.println("Disable Display...");

            mqttClient.client.publish(PUB_TOPIC.c_str(), "n");

            display.display.setContrast(0);
            attraction_mode = false;
        }
    }

    if (attraction_mode && pair_signal) {
        neopixel.set_mode(Neopixel::Mode::RED);
    } else if (pair_signal) {
        neopixel.set_mode(Neopixel::Mode::BLUE);
    } else {
        neopixel.set_mode(Neopixel::Mode::NONE);
    }

    neopixel.update();
}

void search_i2c() {
    Serial.println("Scanning for I2C Device...");

    byte error, address;
    int nDevices;
    nDevices = 0;

    for(address = 1; address < 127; address++ ) {
        Wire.beginTransmission(address);
        error = Wire.endTransmission();
        if (error == 0) {
            Serial.print("I2C device found at address 0x");
            if (address<16) {
                Serial.print("0");
            }
            Serial.println(address,HEX);
            nDevices++;
        } else if (error==4) {
            Serial.print("Unknow error at address 0x");
            if (address<16) {
                Serial.print("0");
            }
            Serial.println(address,HEX);
        }    
    }
    if (nDevices == 0) {
        Serial.println("No I2C devices found\n");
    } else {
        Serial.println("done\n");
    }
}

void callback(char* topic, byte* payload, unsigned int length) {
    if(strcmp(topic, SUB_TOPIC.c_str()) == 0) {
        Serial.println("Received message on valid topic");
        Serial.println(topic);

        if (length > 0 && payload[0] == 'y') {
            pair_signal = true;
        }

        if (length > 0 && payload[0] == 'n') {
            pair_signal = false;
        }
    }
}

uint16_t get_intensity() {
    uint32_t measurements = 0;

    for (size_t i = 0; i < 32; ++i) {
        measurements += analogRead(GPIO_PHOTO);
    }

    measurements /= 32;

    return BRIGHTNESS_MAX - measurements;
}

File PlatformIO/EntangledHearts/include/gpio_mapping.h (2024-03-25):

// Analog Read
const uint8_t GPIO_PHOTO = 2;

// Digital Read, Internal PullUp
const uint8_t GPIO_BUTTON = 6;

//DigitalWrite
const uint8_t GPIO_SDA = 11;

// DigitalWrite
const uint8_t GPIO_SCL = 12;

// DigitalWrite
const uint8_t GPIO_NEOPIXEL = 18;

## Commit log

2023-11-27 ADD: led-stripe added
2023-11-29 ADD: KiCad project initialized
    [KiCad.kicad_pcb, KiCad.kicad_sch]
2023-11-29 ADD: basic PCB-Layout added
    [KiCad.kicad_pcb, KiCad.kicad_sch]
2023-12-06 CHG: minor changes to PCB
    [KiCad.kicad_pcb, KiCad.kicad_sch]
2023-12-06 ADD: right NeoPixel version added
    [EntangledHearts.kicad_pcb, KiCad.kicad_pcb, KiCad.kicad_sch]
2023-12-06 ADD: PCB for NeoPixels started
    [EntangledHearts.kicad_pcb]
2023-12-06 CHG: changed name to FrontPCB
    [FrontPCB.kicad_pcb]
2023-12-06 FIX: fixed missing .kicad_sch files
    [FrontPCB.kicad_sch]
2023-12-06 CHG: changed wiring of front PCB
    [FrontPCB.kicad_pcb, FrontPCB.kicad_sch]
2023-12-11 CHG: components of FrontPCB added
    [FrontPCB.kicad_pcb, FrontPCB.kicad_sch]
2023-12-11 ADD: started with BackPCB
    [BackPCB.kicad_pcb, BackPCB.kicad_sch]
2023-12-12 ADD: charge and flash circuits designed
    [TestPCB.kicad_pcb, TestPCB.kicad_sch]
2023-12-12 ADD: all circuits added
    [TestPCB.kicad_sch]
2023-12-12 ADD: PCB added
    [TestPCB.kicad_pcb, TestPCB.kicad_sch]
2023-12-12 ADD: PCB connections finished
    [2N7002.stp, JS202011SCQN.stp, SFH_3711.stp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]
2023-12-13 ADD: parts arranged in two pcbs
    [TestPCB.kicad_pcb, TestPCB.kicad_sch]
2023-12-13 ADD: 3D-Modell for switch added
    [KMR631NGULCLFS.stp, TestPCB.kicad_pcb]
2023-12-13 CHG: resized textes
    [TestPCB.kicad_sch]
2023-12-13 CHG: files renamed
    [TestPCB_Big.kicad_pcb, TestPCB_Big.kicad_sch, TestPCB_Small.kicad_pcb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]
2023-12-13 CHG: cleanub of vias
    [TestPCB_Big.kicad_pcb]
2023-12-13 ADD: Gerber-Files added
    [TestPCB_Big-B_Cu.gbl, TestPCB_Big-B_Paste.gbp, TestPCB_Big-F_Cu.gtl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]
2023-12-14 CHG: pcb-layouts adopted
    [TestPCB_Big.kicad_pcb, TestPCB_Big.kicad_sch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]
2023-12-15 CHG: changes of today
    [TestPCB_Big.kicad_pcb, TestPCB_Small.kicad_pcb, TestPCB_Small.kicad_sch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]
2023-12-21 ADD: new Project initialized
    [2N7002.stp, BackPCB.kicad_pcb, BackPCB.kicad_sch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]
2024-01-06 ADD: schematics for main circuits added
    [EntangledHearts.kicad_sch]
2024-01-08 ADD: all parts added
    [EntangledHearts.kicad_sch]
2024-01-09 ADD: final touches for first plot
    [EntangledHearts.kicad_sch]
2024-01-18 CHG: GPIO photo low-active
    [EntangledHearts.kicad_sch]
2024-01-25 CHG: new MOSFET-Footprint added
2024-01-27 ADD: flashing circuit added
    [EntangledHearts.kicad_sch]
2024-01-29 ADD: all footprints added
    [EntangledHearts.kicad_pcb, EntangledHearts.kicad_sch]
2024-02-02 ADD: first pcbs added
    [EntangledHearts.kicad_pcb, EntangledHearts.kicad_sch]
2024-02-07 CHG cleanup of Schematics done
    [EntangledHearts.kicad_pcb, EntangledHearts.kicad_sch]
2024-02-07 ADD: further progress
    [EntangledHearts.kicad_pcb, EntangledHearts.kicad_sch]
2024-02-08 CHG: some minor changes
    [EntangledHearts.kicad_pcb, EntangledHearts.kicad_sch]
2024-02-09 ADD: all parts connected
    [EntangledHearts.kicad_pcb, EntangledHearts.kicad_sch]
2024-02-09 ADD: all errors in PCB fixed
    [EntangledHearts.kicad_pcb, EntangledHearts.kicad_sch]
2024-02-09 ADD: 3D-File for connector added
    [EntangledHearts.kicad_pcb, S2B-PH-SM4-TB.stp]
2024-02-11 CHG: rewiring of front pcb
    [EntangledHearts.kicad_pcb]
2024-02-11 ADD: all components on front PCB placed
    [EntangledHearts.kicad_pcb]
2024-02-11 ADD: all components connected
    [EntangledHearts.kicad_pcb, EntangledHearts.kicad_sch]
2024-02-11 CHG: Alignment changed
    [EntangledHearts.kicad_pcb]
2024-02-11 ADD: mousebites added
    [EntangledHearts.kicad_pcb]
2024-02-12 ADD: Gerberfiles added
    [EntangledHearts-B_Cu.gbr, EntangledHearts-B_Mask.gbr, EntangledHearts-B_Paste.gbr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]
2024-02-24 DEL: removed KiCad/_old/
    [2N7002.stp, BackPCB.kicad_pcb, BackPCB.kicad_sch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]
2024-02-24 ADD: initialized PlatformIO project
    [EntangledHearts-B_Cu.gbr, EntangledHearts-B_Mask.gbr, EntangledHearts-B_Paste.gbr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]
2024-02-24 ADD: Examples for all components added
    [EntangledHearts.kicad_sch]
2024-03-07 ADD: current state added
2024-03-16 ADD: simple communication bewtween devices added
2024-03-17 ADD: First FreeCAD Model added
    [EntangledHearts.FCStd]
2024-03-23 ADD: Front added
    [EntangledHearts.FCStd]
2024-03-24 ADD: Housing finished
    [EntangledHearts.FCStd]
2024-03-24 CHG: changed button dimensions
    [EntangledHearts.FCStd]
2024-03-24 ADD: files for 3D-printing added
    [Bottom_Body.stl, Button_Body.stl, Connector_Body.stl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]
